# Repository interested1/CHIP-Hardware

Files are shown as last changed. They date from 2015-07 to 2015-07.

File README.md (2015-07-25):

# CHIP-Hardware
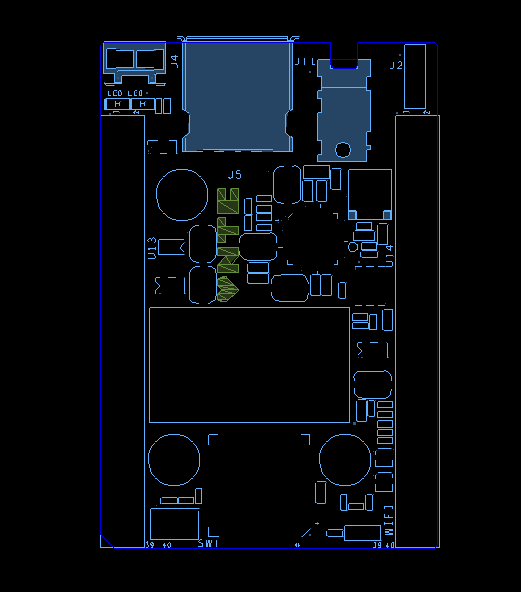
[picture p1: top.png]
CHIP


#License
<br />This work is licensed under a <a rel="license" href="http://creativecommons.org/licenses/by-sa/3.0/us/">Creative Commons Attribution-ShareAlike 3.0 United States License</a>.

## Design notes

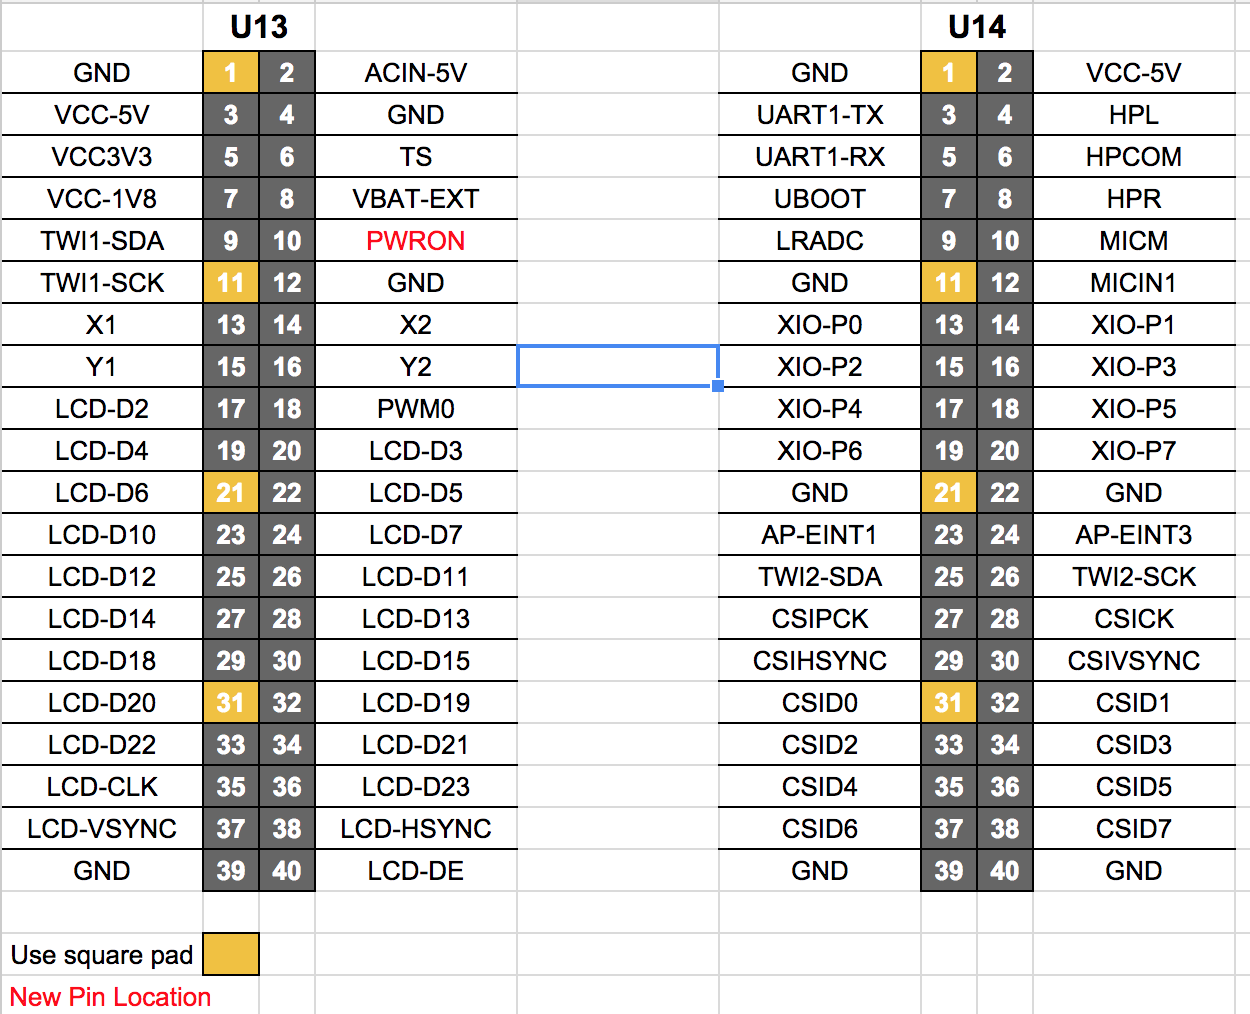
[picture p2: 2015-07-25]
CHIP_ALPHA_V02_Pinouts.png

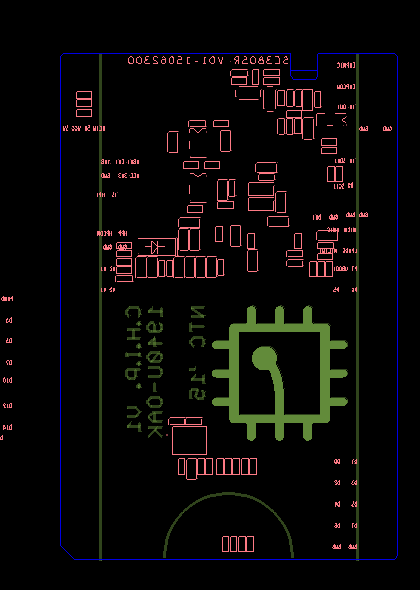
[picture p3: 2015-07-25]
bottom.png

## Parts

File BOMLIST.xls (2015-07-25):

Bill Of Materials
Item | Quantity | Reference | Part | Footprint
1 | 1 | ANT1 | ANT | WIFI-1206
2 | 1 | ANT2 | NC-ANT | WIFI-ANT-SD73412-011H1_3A
3 | 2 | C1,C5 | 18pF-1% | C0201
4 | 15 | C2,C3,C4,C13,C14,C16,C17,C18,C19,C21,C32,C45,C57,C75,C77 | 10uF | CC0603
5 | 7 | C9,C22,C24,C26,C37,C49,C145 | 1uF | CC0402
6 | 16 | C10,C11,C12,C25,C27,C28,C29,C50,C59,C65,C66,C68,C70,C71,C74,C76 | 4.7uF | CC0603
7 | 1 | C15 | 102 | CC0402
8 | 1 | C20 | 102 | C0201
9 | 9 | C35,C54,C58,C64,C69,C72,C148,C151,C152 | 104 | C0201
10 | 4 | C47,C48,C52,C60 | NC | R0402
11 | 1 | C51 | 8P | C0402
12 | 1 | C53 | 22pF | C0201
13 | 1 | C55 | 271 | C0201
14 | 1 | C56 | 331 | C0201
15 | 2 | C67,C73 | 47pF | C0201
16 | 2 | C78,C79 | 22uF | CC0805
17 | 1 | C188 | 4.7u/6.3V | CC0603
18 | 1 | C294 | 100pF | C0201
19 | 1 | D1 | POWER | D0603
20 | 1 | D2 | MODE | D0603
21 | 1 | D16 | 1N5819 | SOD123H14A
22 | 1 | D18 | BAT54S | SOT-23
23 | 1 | J1 | BATTARY | CON2-PT2_54H7_1A
24 | 1 | J2 | TVOUT&MIC | CON3-PT2_54-2_5X7_57H16_3A
25 | 1 | J4 | USB-MINI-SOCKET | USB-MIC-A01SB141BH2_4A
26 | 1 | J5 | USB-MINI-SOCKET | USB_AF-011Z_45H5_2A
27 | 1 | J11 | HXQKPJ-342H | PJ-033SMTH4A
28 | 6 | L2,L3,L4,L5,L6,L8 | 2.2uH-DCR<0.1R-1.5A/ELL4LG2R2NA | L3518
29 | 1 | L9 | 1.8uH | L0603
30 | 2 | OR4,R75 | 6K8-1% | C0201
31 | 1 | Q4 | MMBT3904 | SOT-23
32 | 2 | RN1,RN2 | 0R*4 | RN0201
33 | 7 | R1,R2,R3,R4,R6,R18,R103 | 2K2 | C0201
34 | 1 | R7 | 0R03 | R0805
35 | 1 | R8 | 20K | C0201
36 | 2 | R9,R82 | 1R | R0402
37 | 6 | R10,R11,R55,R56,R70,R87 | 10k | C0201
38 | 8 | R12,R39,R40,R41,R43,R84,R85,R414 | 0R | C0201
39 | 2 | R13,R54 | 200K-1% | C0201
40 | 2 | R14,R78 | 100K-1% | C0201
41 | 1 | R15 | 150K-1% | C0201
42 | 2 | R16,R17 | 47K | C0201
43 | 3 | R19,R45,R46 | 0R | R0402
44 | 1 | R20 | 2K | R0402
45 | 2 | R47,R61 | NC-0R | R0402
46 | 5 | R48,R49,R51,R52,R53 | 33K | C0201
47 | 1 | R50 | NC | C0201
48 | 1 | R57 | 27K-1% | C0201
49 | 2 | R58,R59 | NC-10K | C0201
50 | 1 | R60 | 75R | C0201
51 | 2 | R62,R63 | NC/0R | C0201
52 | 3 | R65,R66,R105 | 100K | C0201
53 | 1 | R74 | 510K | C0201
54 | 1 | R79 | 442K-1% | C0201
55 | 1 | R80 | NC-0R | R0805
56 | 1 | R81 | 0R | R0805
57 | 4 | R83,R86,R102,R113 | 1K | C0201
58 | 1 | R88 | 1M | C0201
59 | 2 | R100,R101 | 24R | C0201
60 | 1 | R192 | 1.5K | C0201
61 | 1 | SW1 | KEY-2PIN_0 | SW_4P_TC3061B
62 | 1 | TP2 | DC3-SET | TP40_SMD
63 | 3 | TP3,TP5,TP6 | LS | PAD6D3
64 | 1 | TP4 | VMIC | TP40_SMD
65 | 1 | TP7 | PMU-GPOI1 | TP40_SMD
66 | 1 | U1 | R8M | R8M_LGA128_SSQ0_8
67 | 1 | U3 | AXP209 | QFN49_0_4H0_8A
68 | 1 | U4 | LP3220SAB5F/SY8088 | SOT23_5H14A
69 | 1 | U9 | 8723BS | QFN44-AP6476-12X12H1_6A
70 | 2 | U10,U15 | LPW5210B5F | SOT23_5H14A
71 | 1 | U11 | LP6226/SY7208 | SOT23-6
72 | 1 | U12 | LP3220SAB5F\SY8088 | SOT23_5H14A
73 | 2 | U13,U14 | LCD_CN | CON2X20-PT2_54-5_2X31_2H2A
74 | 1 | U27 | PCF8574ARGYR | QFN20-PT0_5-3_65X4_65H1A
75 | 1 | X1 | 24M-20pF-10PPM | CRYSTAL-4P-3225-H1A

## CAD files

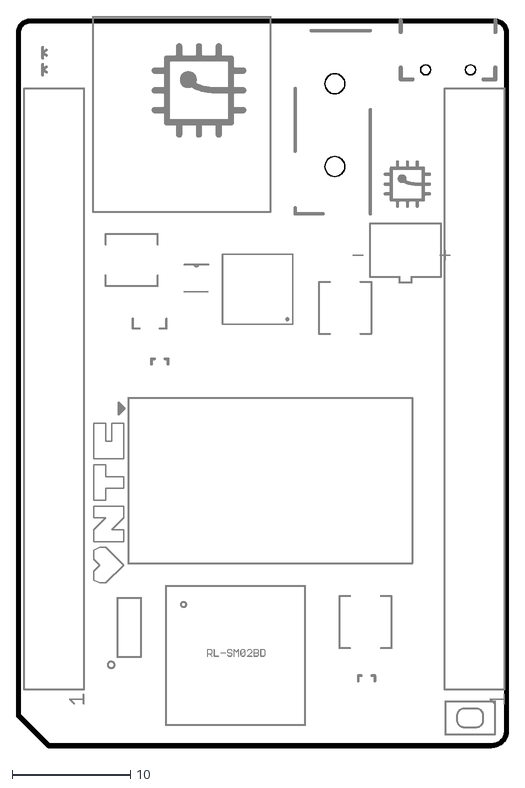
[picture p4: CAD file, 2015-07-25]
CHIP Prop v0.3-top.dxf
41.7 x 61.9

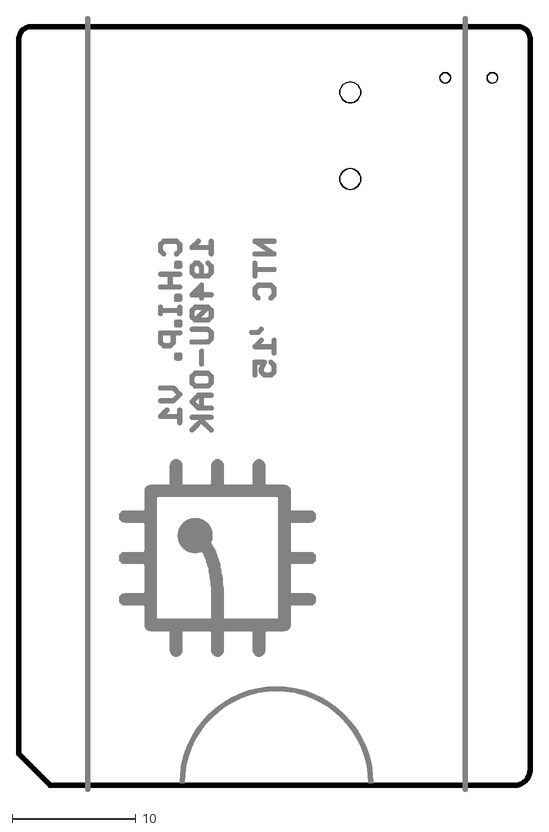
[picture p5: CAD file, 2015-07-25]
CHIP Prop v0.3-bot.dxf
41.7 x 62.6

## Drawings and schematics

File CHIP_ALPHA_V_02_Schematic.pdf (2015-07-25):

# Schematics Index：

# P01: REVISION HISTORY

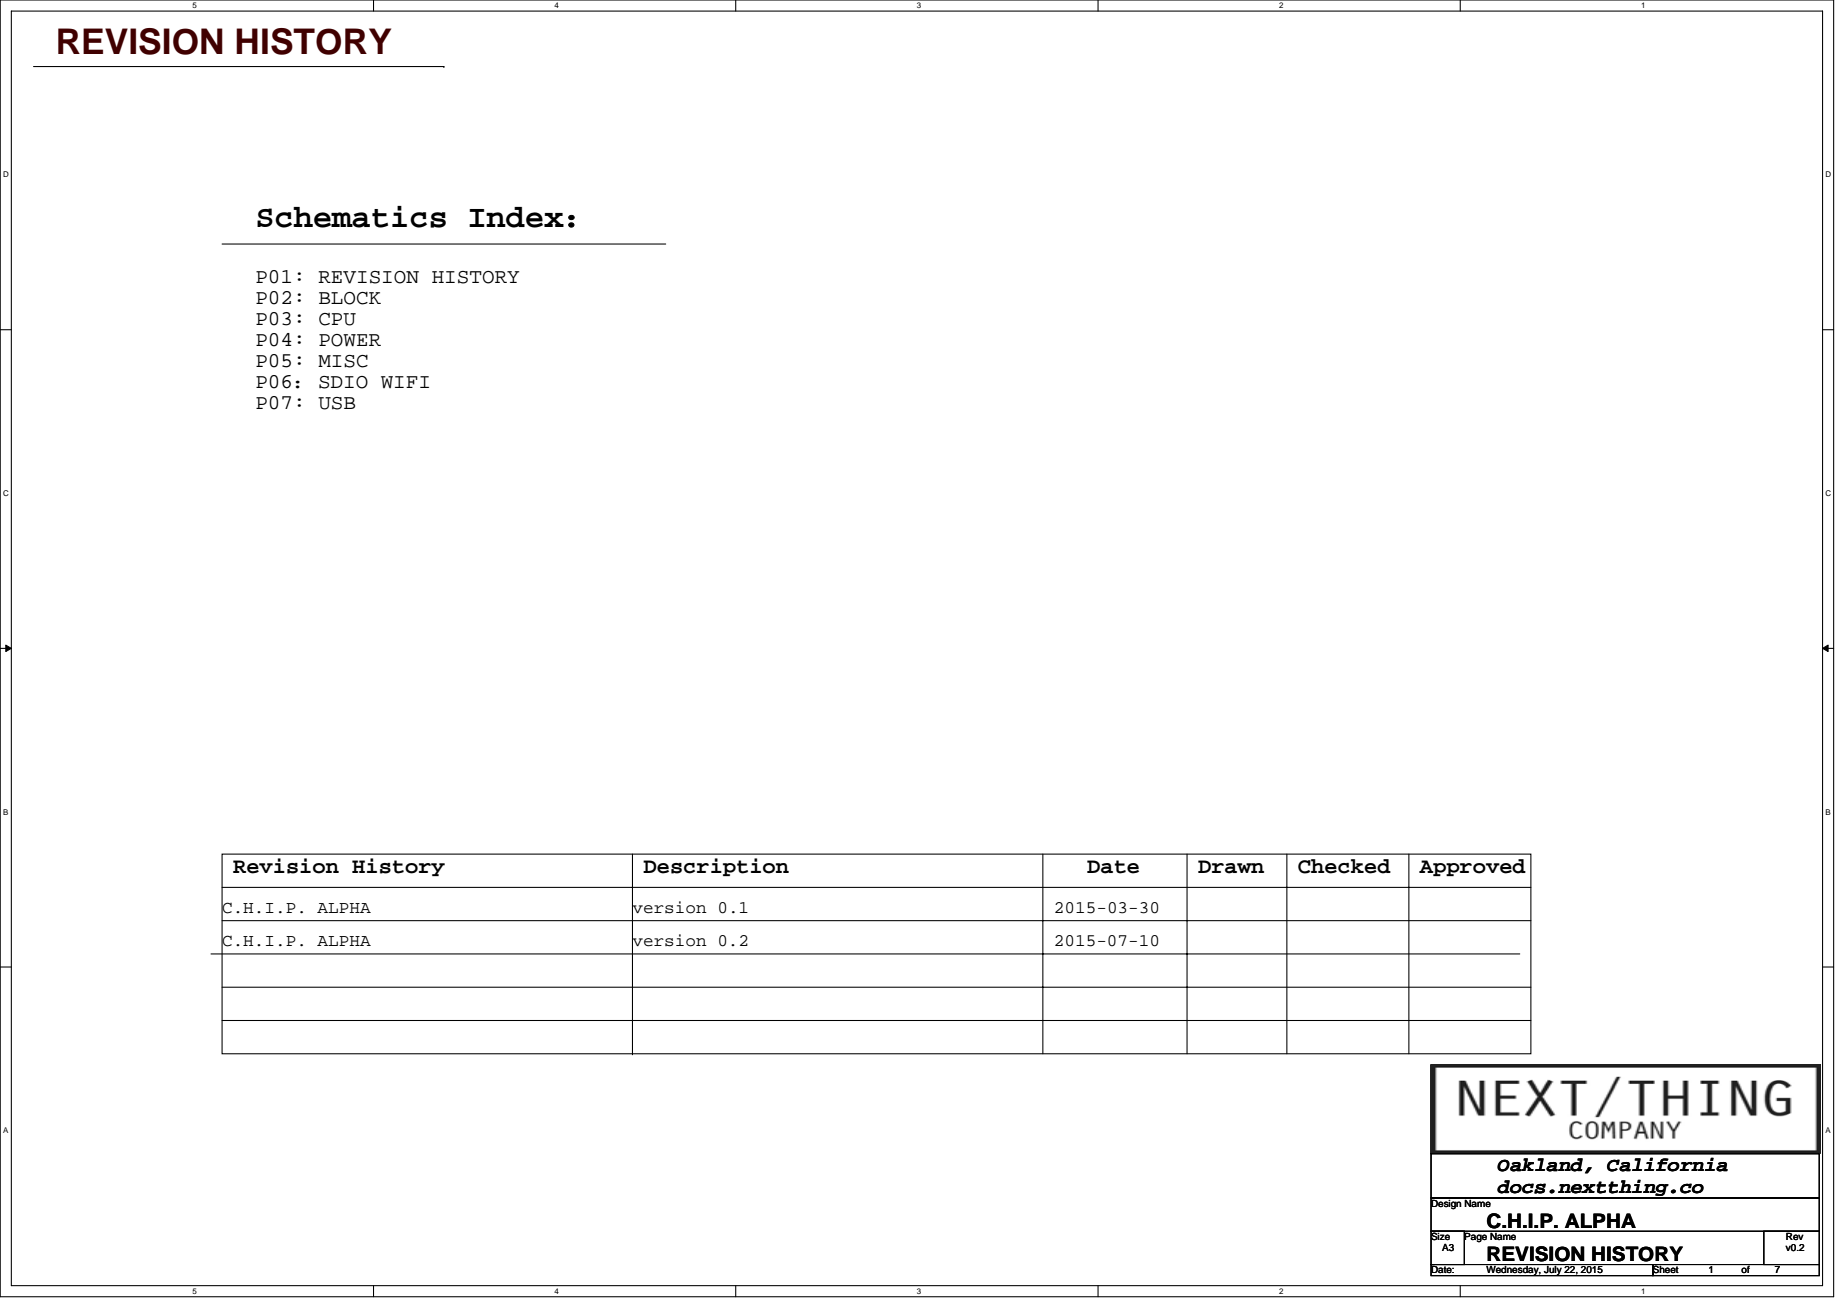
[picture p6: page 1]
P02: BLOCK P03: CPU P04: POWER P05: MISC P06：SDIO WIFI P07: USB; REVISION HISTORY; Design Name

Revision History | Description | Date | Drawn | Checked | Approved

C.H.I.P. ALPHA | version 0.1 | 2015-03-30
C.H.I.P. ALPHA | version 0.2 | 2015-07-10

Oakland, California
docs.nextthing.co
C.H.I.P. ALPHA

Size A3 | Page Name REVISION HISTORY REVISION HISTORY REVISION HISTORY | Rev v0.2 v0.2 v0.2

Date: Wednesday, July 22, 2015 Wednesday, July 22, 2015 Wednesday, July 22, 2015 | Sheet 1 1 1 of 7 7 7

# BATT

# DCIN

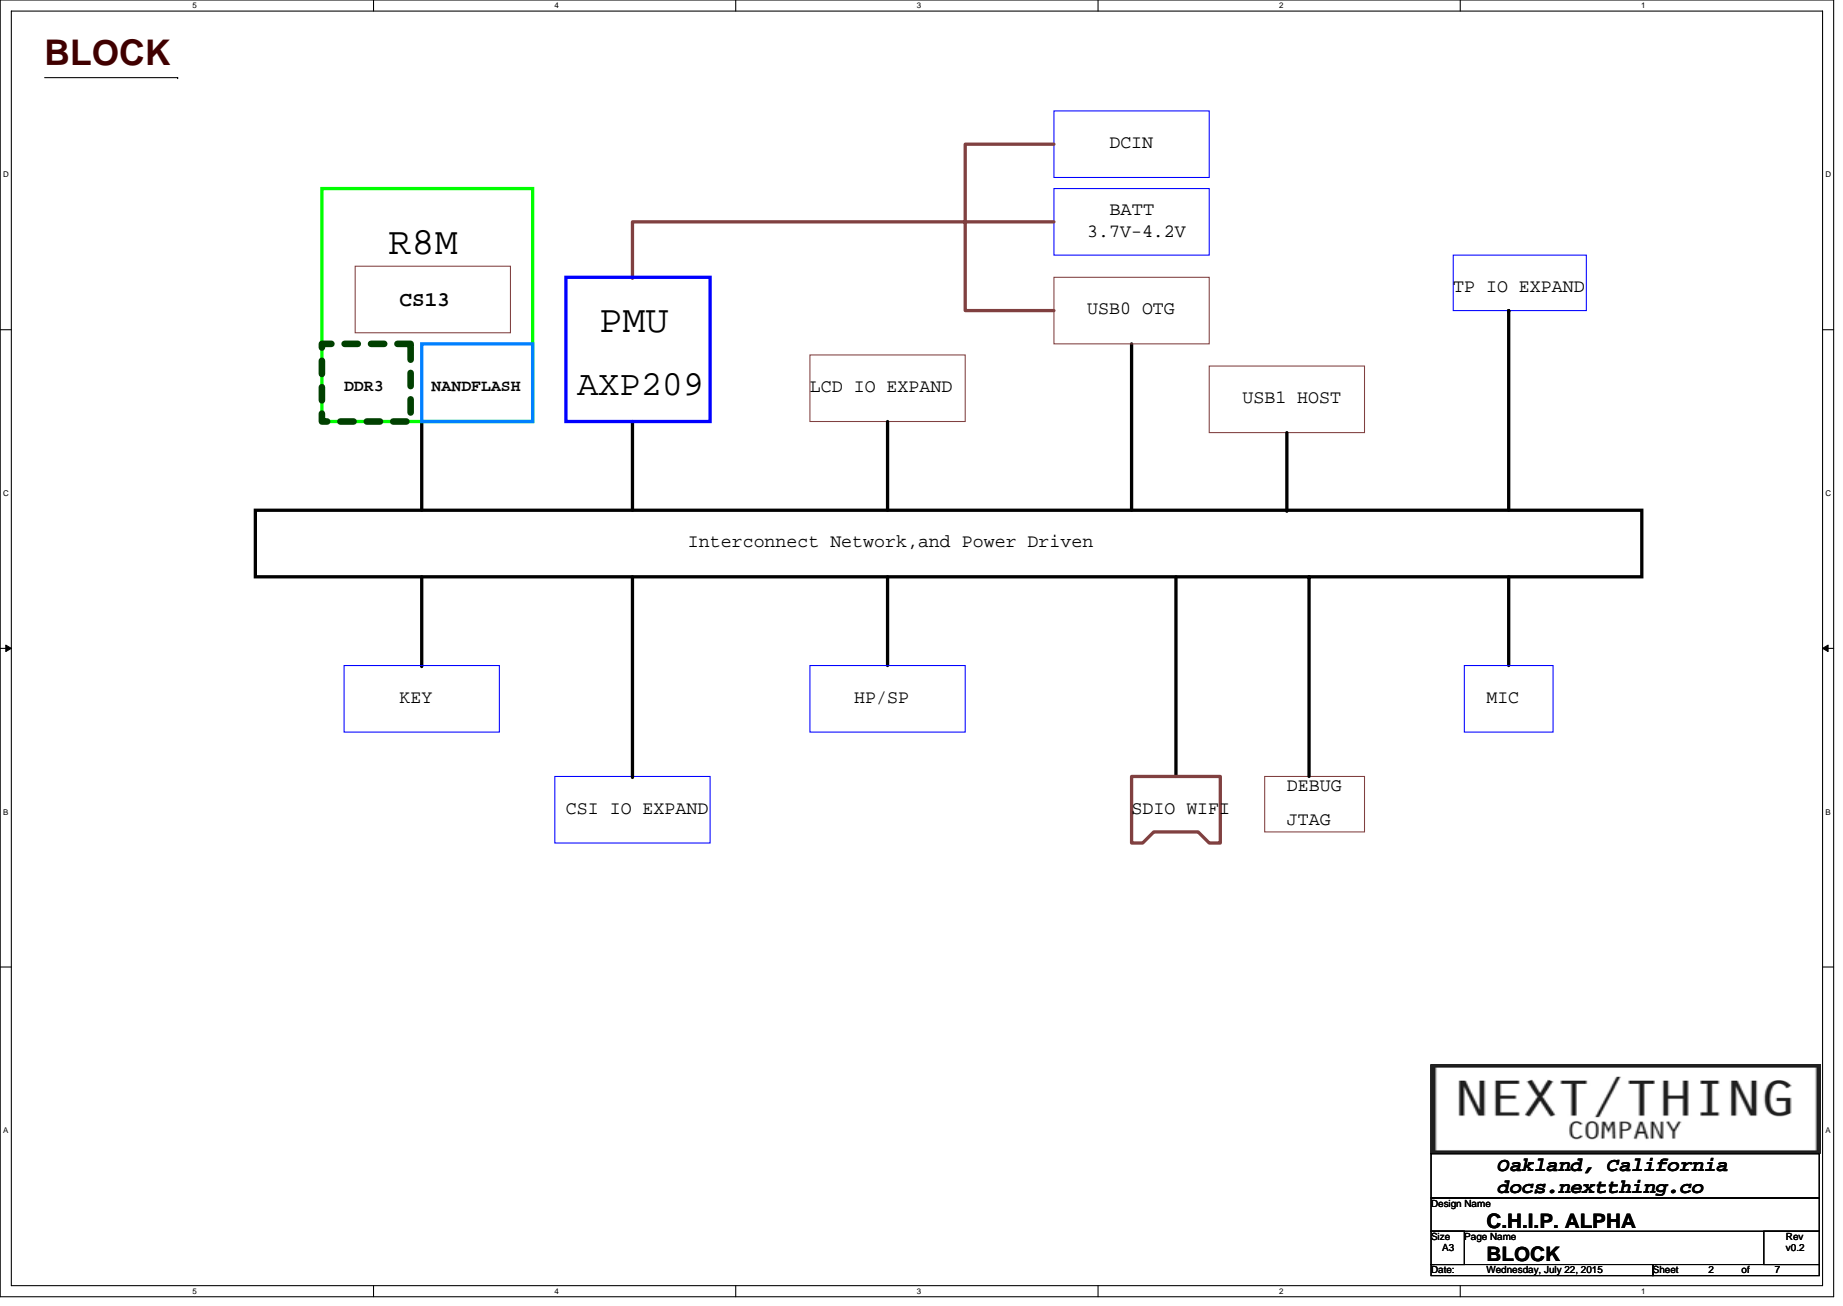
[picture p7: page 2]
SDIO WIFI; USB0 OTG; DEBUG; JTAG; KEY; PMU; AXP209; MIC; BLOCK; NANDFLASH; USB1 HOST; DDR3

TP IO EXPAND

LCD IO EXPAND

Interconnect Network,and Power Driven

CSI IO EXPAND

Oakland, California
docs.nextthing.co

BLOCK BLOCK BLOCK | v0.2 v0.2 v0.2

Wednesday, July 22, 2015 Wednesday, July 22, 2015 Wednesday, July 22, 2015 | 2 2 2 7 7 7

# CPU

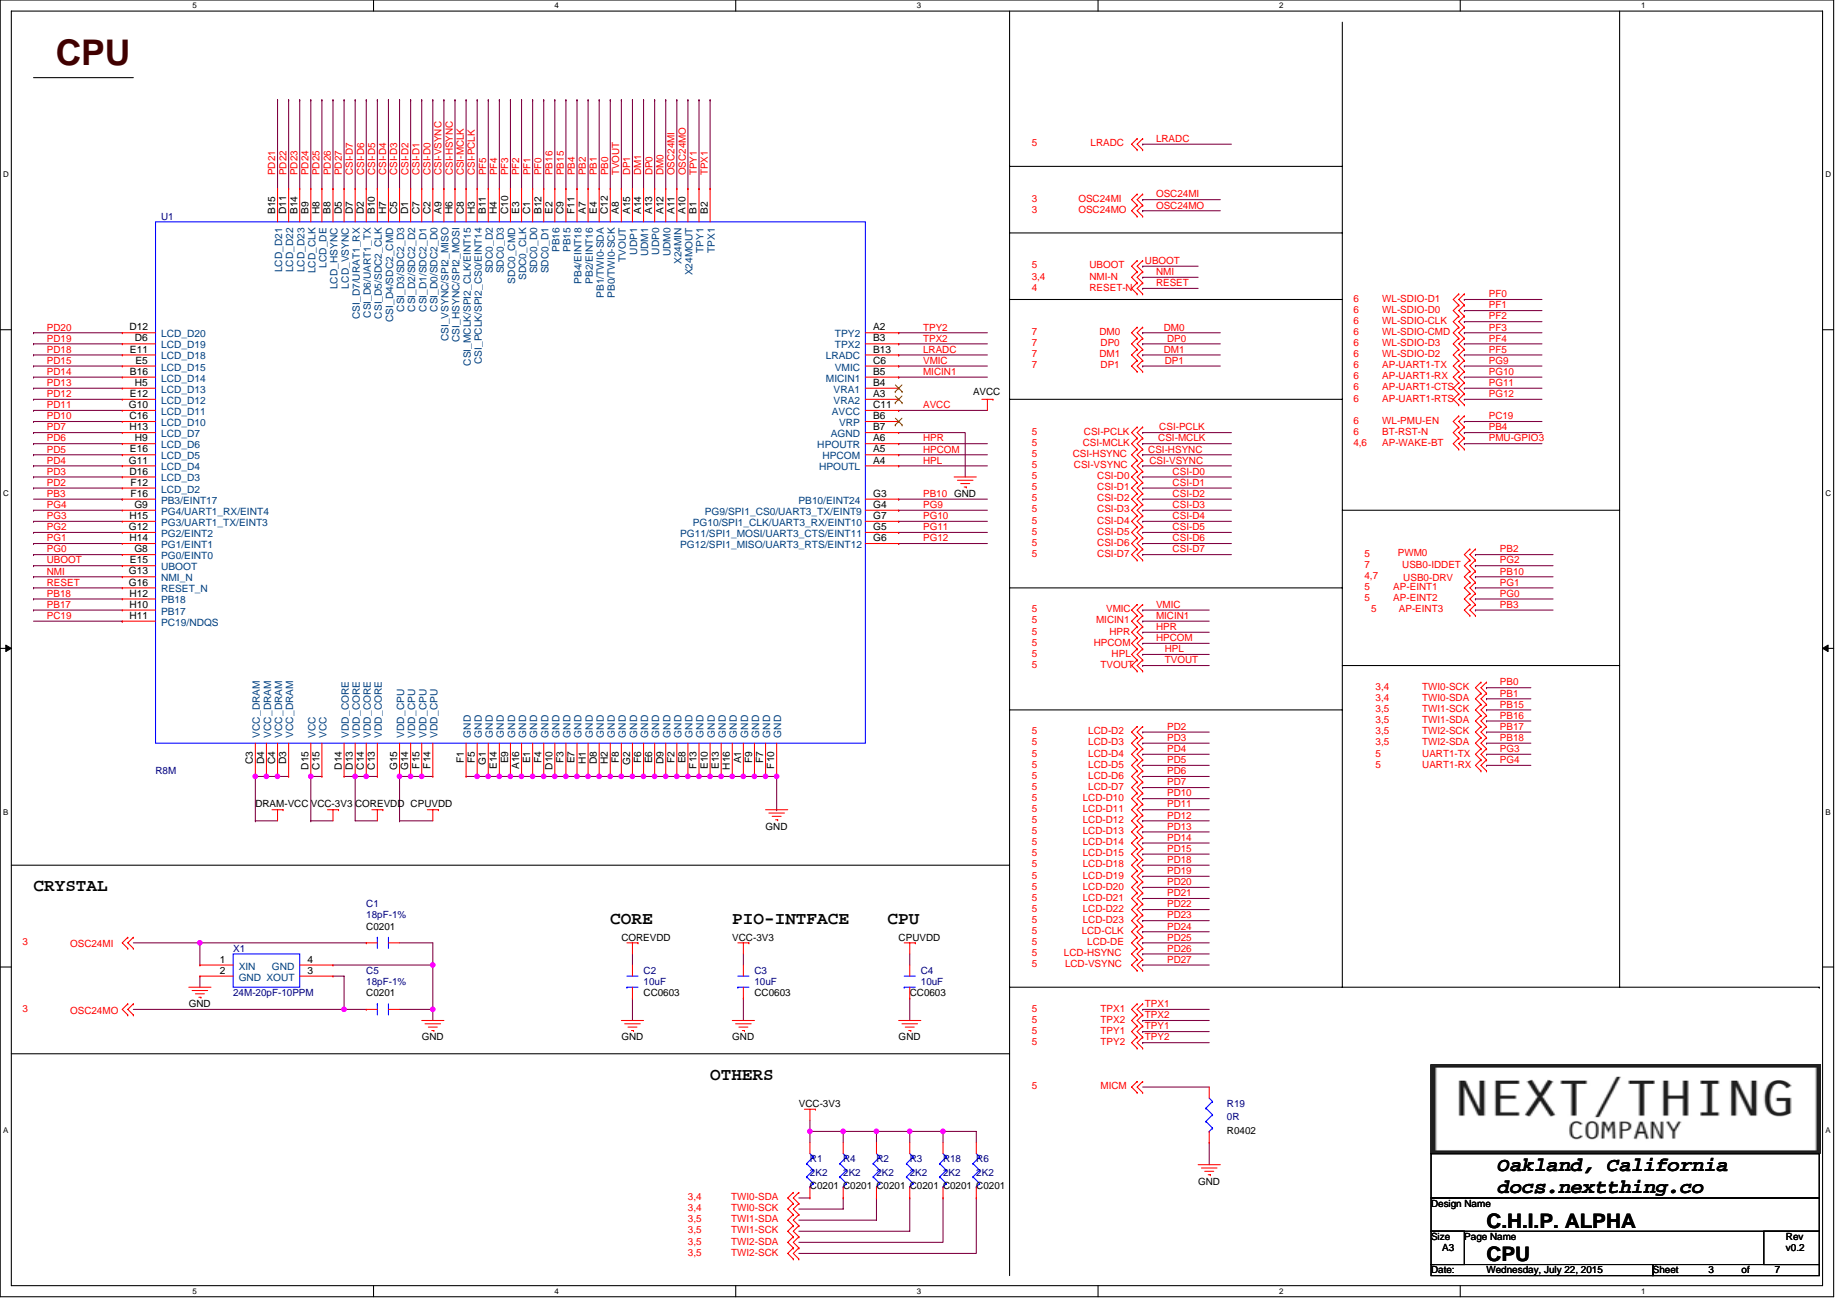
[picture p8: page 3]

DRAM-VCC VCC-3V3 COREVDD CPUVDD

CPU CPU CPU | v0.2 v0.2 v0.2

Wednesday, July 22, 2015 Wednesday, July 22, 2015 Wednesday, July 22, 2015 | 3 3 3 7 7 7

# POWER/PMU

# IPSOUT TO 5V FOR SYS

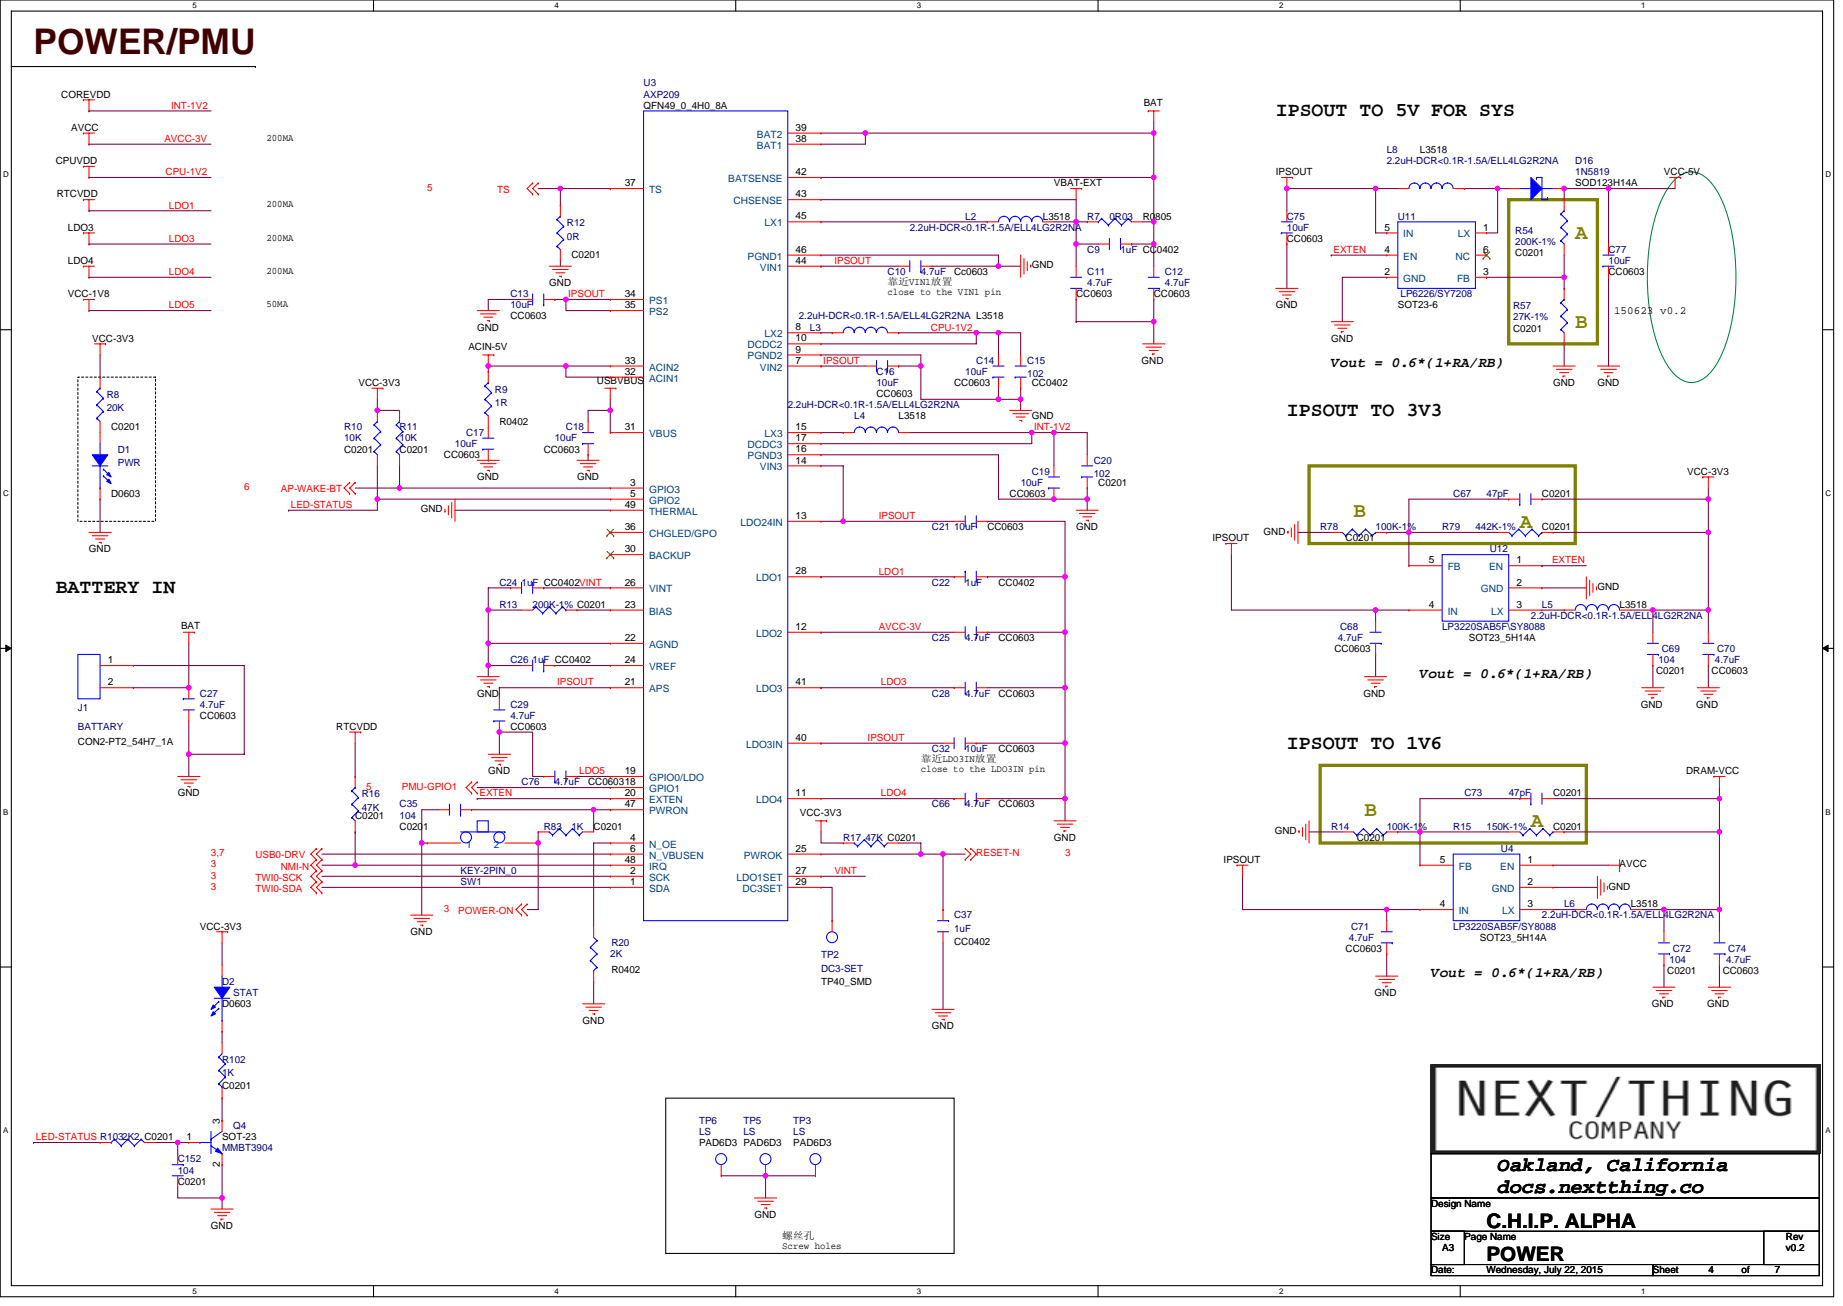
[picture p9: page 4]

靠近VIN1放置
close to the VIN1 pin

靠近LDO3IN放置
close to the LDO3IN pin

POWER POWER POWER | v0.2 v0.2 v0.2

Wednesday, July 22, 2015 Wednesday, July 22, 2015 Wednesday, July 22, 2015 | 4 4 4 7 7 7

# MISC

## Note:

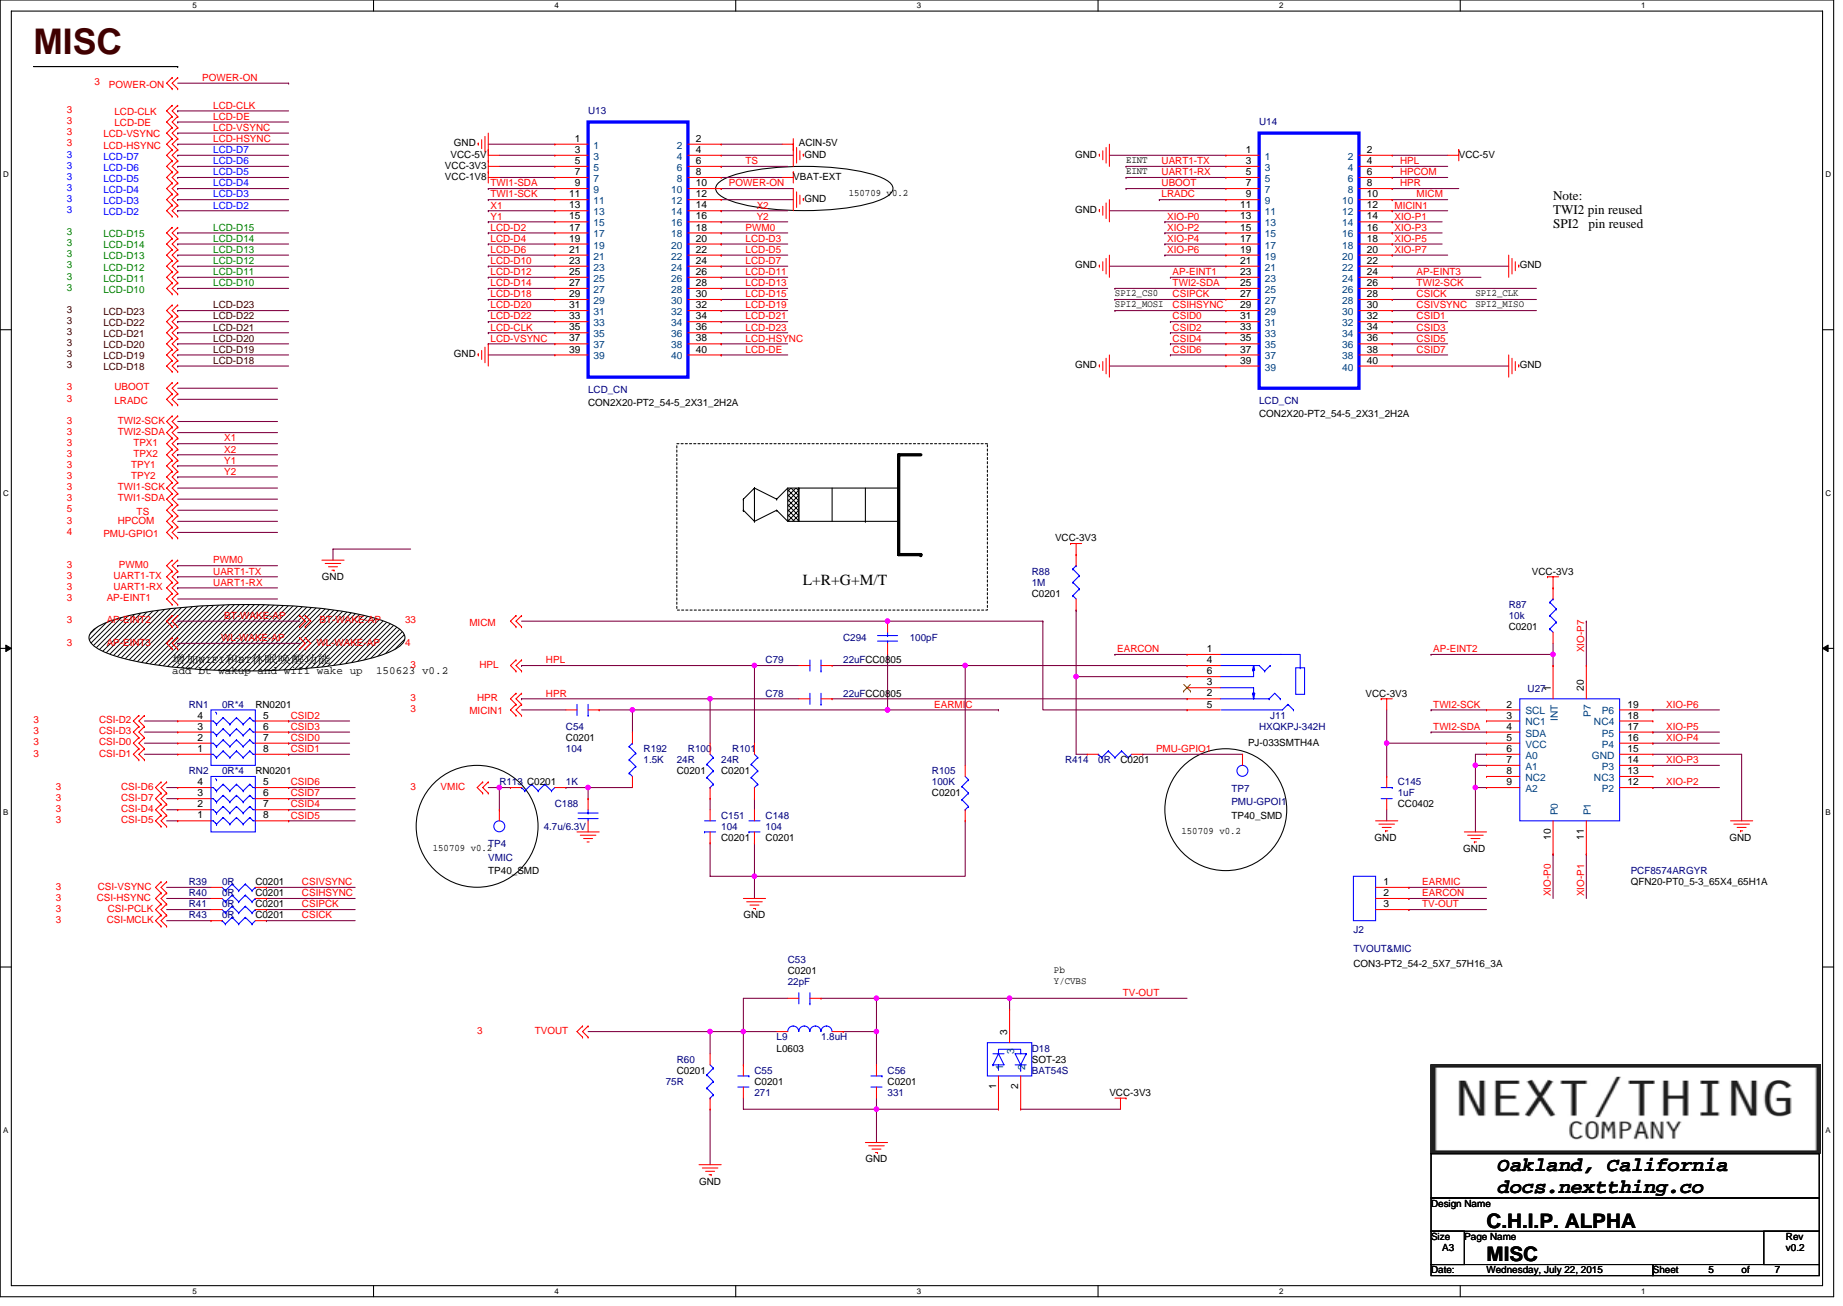
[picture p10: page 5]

增加WIFI和BT休眠唤醒功能
add bt wakup and wifi wake up 150623 v0.2

MISC MISC MISC | v0.2 v0.2 v0.2

Wednesday, July 22, 2015 Wednesday, July 22, 2015 Wednesday, July 22, 2015 | 5 5 5 7 7 7

A

B

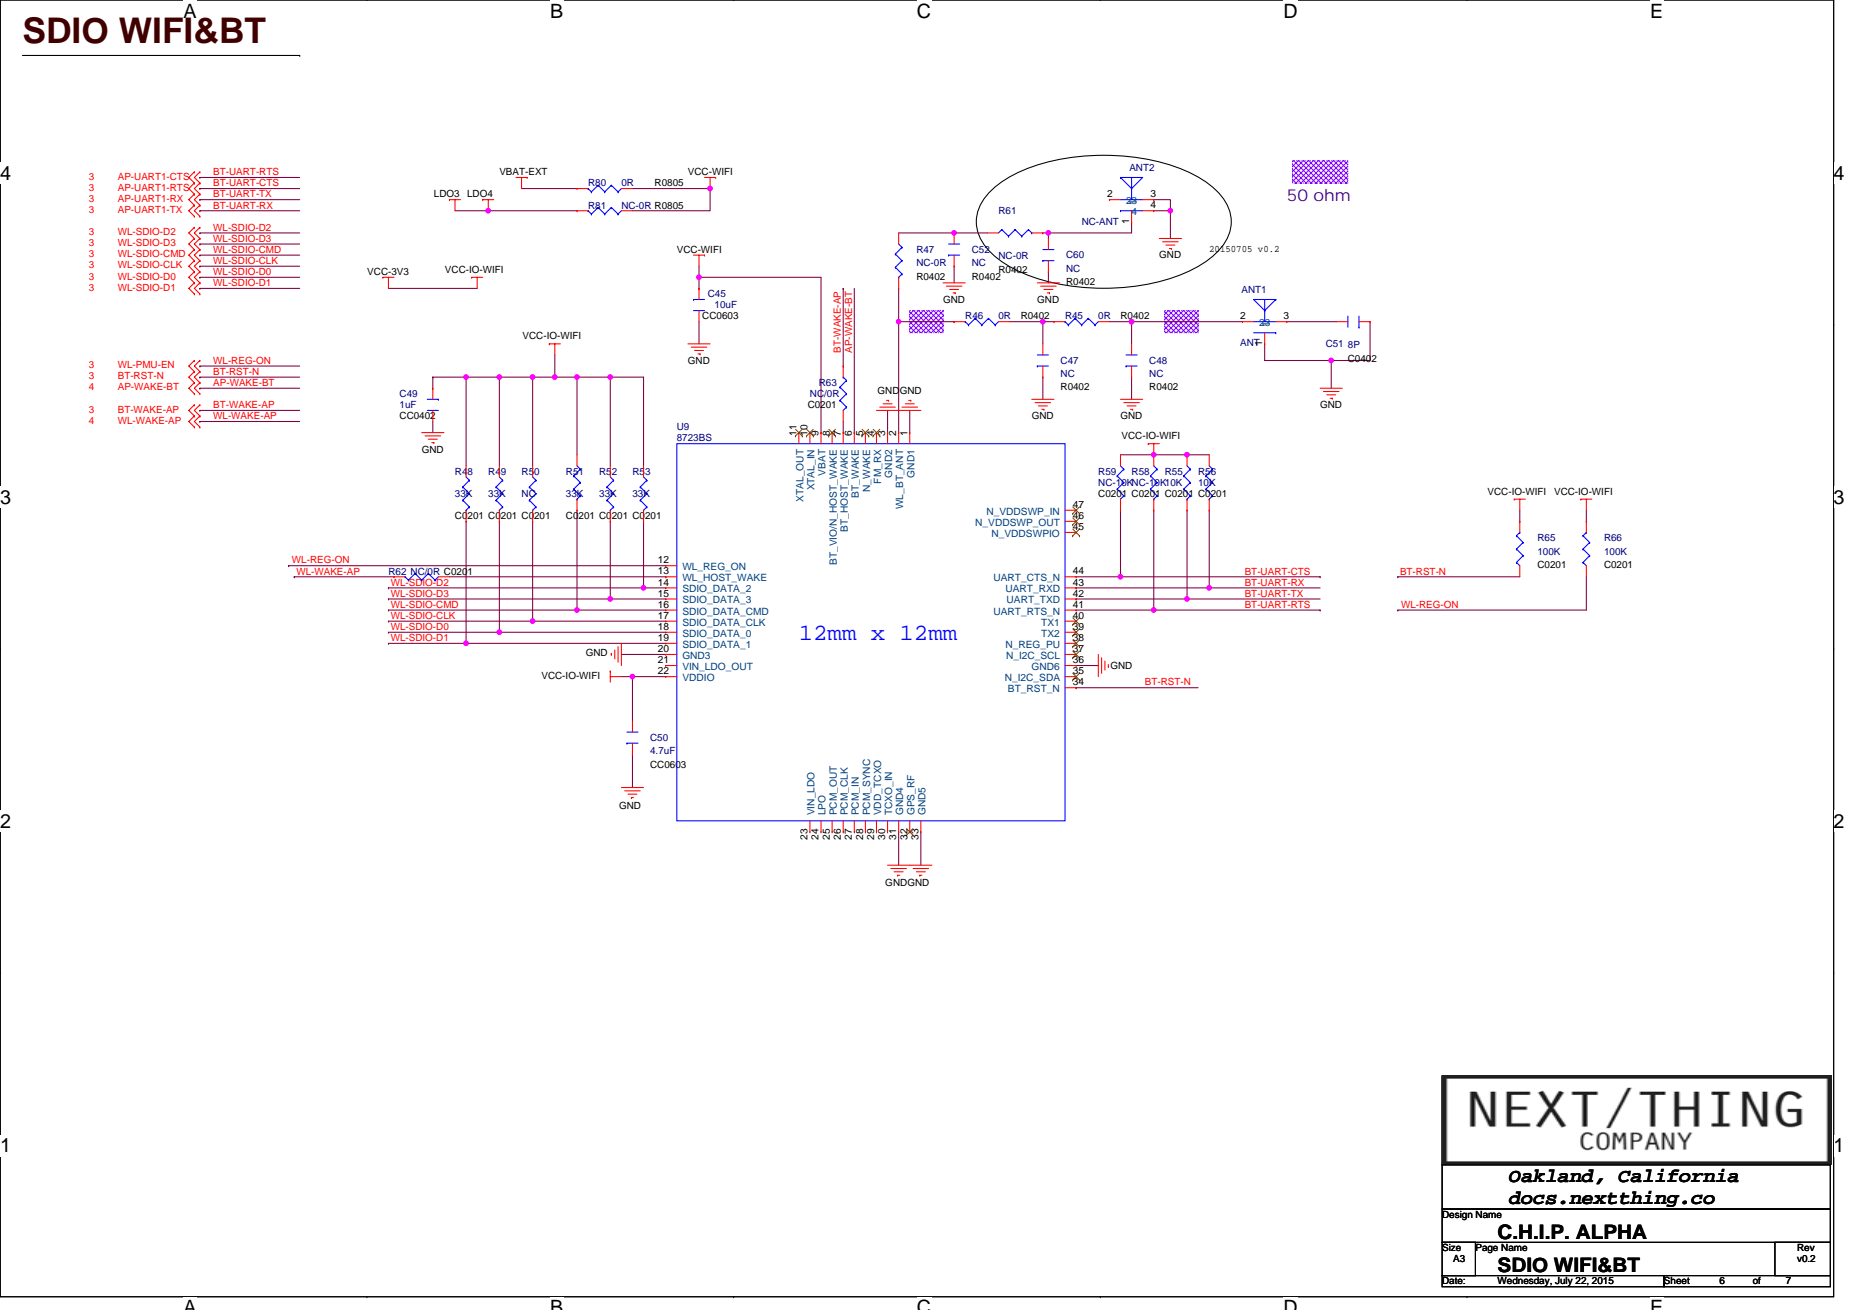
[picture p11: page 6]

VCC-IO-WIFI

SDIO WIFI&BT SDIO WIFI&BT SDIO WIFI&BT | v0.2 v0.2 v0.2

Wednesday, July 22, 2015 Wednesday, July 22, 2015 Wednesday, July 22, 2015 | 6 6 6 7 7 7

# USB

# USB

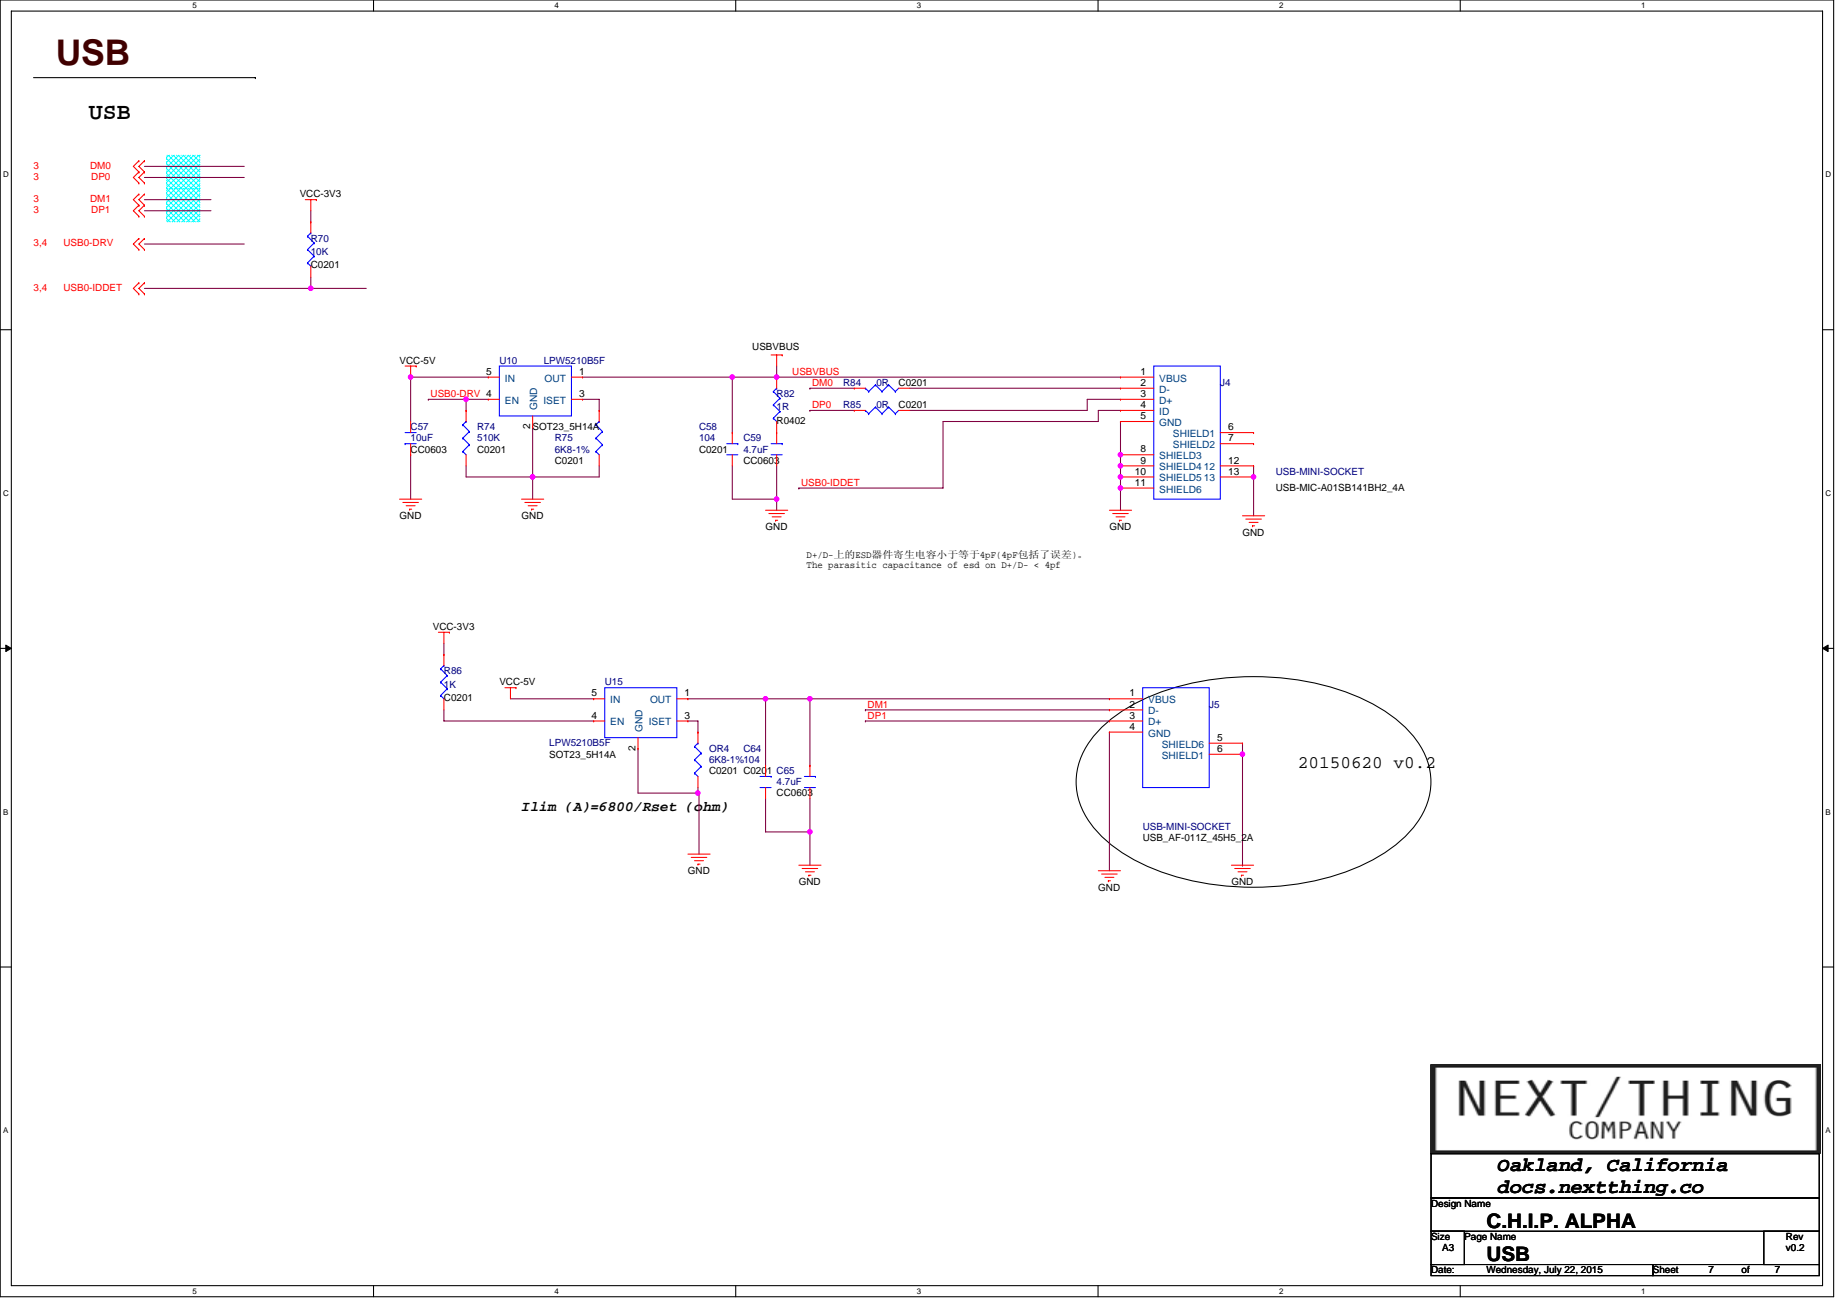
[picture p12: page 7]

D+/D-上的ESD器件寄生电容小于等于4pF(4pF包括了误差)。
The parasitic capacitance of esd on D+/D- < 4pf

USB USB USB | v0.2 v0.2 v0.2

Wednesday, July 22, 2015 Wednesday, July 22, 2015 Wednesday, July 22, 2015 | 7 7 7
